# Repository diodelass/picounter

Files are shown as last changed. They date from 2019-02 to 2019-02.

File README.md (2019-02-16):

# PiCounter
## Frequency counter for experimental physics using the Raspberry Pi

### Overview
This repository holds schematics and information for the PiCounter, a firmwareless and fairly simple device for accurately measuring
the frequency of an electrical signal using the Raspberry Pi to control data collection. The device has the following features:
- Maximum count rate of up to 40 MHz
- 32-bit count capacity
- Two channels
- AND/OR coincidence mode for cosmic ray detection and similar applications
- Low total cost of manufacture
- Highly stable and accurate quartz-based counting gate timer
- 1/256-second counting time resolution
- Support for arbitrarily long counting times
- Side-mounted serial interface breakout for easy attachment of debug cables
- Support for external clock input

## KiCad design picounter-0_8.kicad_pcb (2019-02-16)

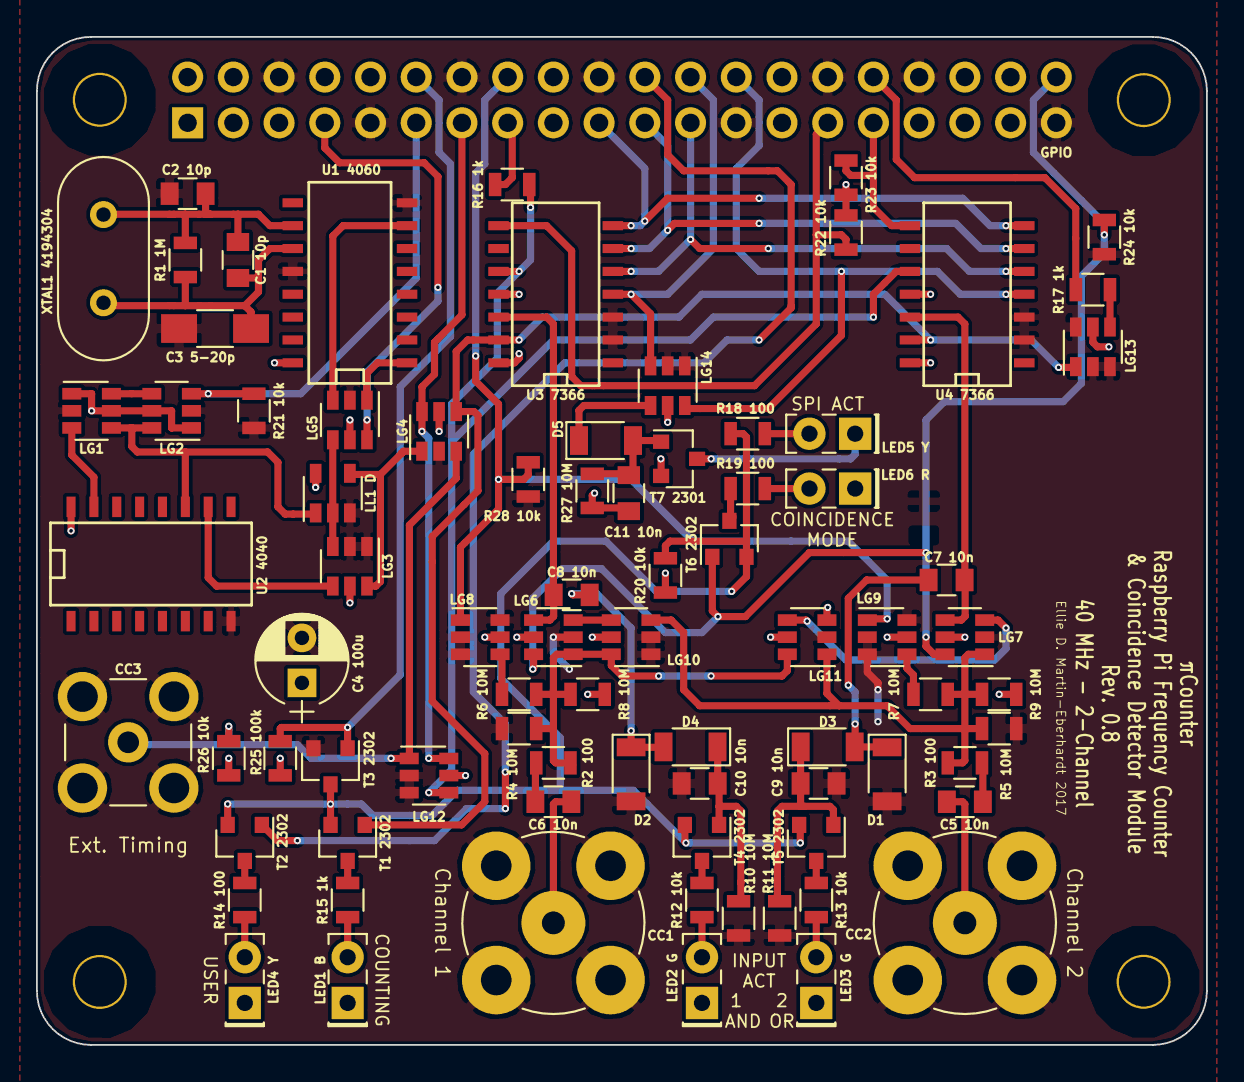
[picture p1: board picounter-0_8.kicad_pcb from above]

Board: 2 copper layers, 65.0 x 56.0 mm, 85 parts (1 on the bottom side), 2 nets.

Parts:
C1 10p, C2 10p, C5 10n, C6 10n, C7 10n, C8 10n, C9 10n, C10 10n, C11 10n: C_0805
C3 5-20p: C_1206_HandSoldering
C4 100u: CP_Radial_D5.0mm_P2.50mm
CC1, CC2: bnc-ci
CC3: SMB_Straight
D1, D2, D3, D4, D5: D_1206
GPIO: 40HAT; Socket_Strip_Straight_2x20
H1, H2, H3, H4: 3mm_Mounting_Hole; NPTH_3mm_ID
LED1 B, LED2 G, LED3 G, LED4 Y, LED5 Y, LED6 R: LED_Rectangular_W5.0mm_H2.0mm
LG1, LG2, LG3, LG4, LG5, LG6, LG7, LG8, LG9, LG10, LG11, LG12, LG13, LG14: SOT-23-6
LL1 D: SOT-23-5
R1 1M, R2 100, R3 100, R4 10M, R5 10M, R6 10M, R7 10M, R8 10M, R9 10M, R10 10M, R11 10M, R12 10k, R13 10k, R14 100, R15 1k, R16 1k, R17 1k, R18 100, R19 100, R20 10k, R21 10k, R22 10k, R23 10k, R24 10k, R25 100k, R26 10k, R27 10M, R28 10k: R_0805
T1 2302, T2 2302, T3 2302, T4 2302, T5 2302, T6 2302, T7 2301: SOT-23
U1 4060, U2 4040: SO-16-N
U3 7366, U4 7366: SOIC-14_N
XTAL1 4194304: Crystal_HC18-U_Vertical

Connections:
/P5V_HAT: C4 100u.1, C11 10n.1, GPIO.2, GPIO.4, LED1 B.1, LED2 G.1, LED3 G.1, LED4 Y.1, LED6 R.1, LG1.1, LG1.5, LG2.1, LG2.5, LG3.5, LG4.5, LG5.5, LG6.5, LG7.5, LG8.5, LG9.5, LG10.5, LG11.3, LG11.5, LG12.5, LG13.5, LG14.5, LL1 D.5, R8 10M.1, R9 10M.2, R20 10k.1, R22 10k.1, R23 10k.1, R25 100k.2, R26 10k.2, R27 10M.1, T7 2301.2, U1 4060.16, U2 4040.16, U3 7366.11, U3 7366.14, U4 7366.11, U4 7366.14
GND: C2 10p.2, C3 5-20p.2, C4 100u.2, C9 10n.1, C10 10n.1, CC1.2, CC2.2, CC3.2, D1.2, D2.2, GPIO.6, GPIO.9, GPIO.14, GPIO.20, GPIO.25, GPIO.30, GPIO.34, GPIO.39, LG1.2, LG2.2, LG3.1, LG3.2, LG4.2, LG5.2, LG6.2, LG7.2, LG8.2, LG8.3, LG8.6, LG9.2, LG9.3, LG9.6, LG10.1, LG10.2, LG11.2, LG12.2, LG12.3, LG13.2, LG13.3, LG13.6, LG14.1, LG14.2, LL1 D.3, R4 10M.2, R5 10M.2, R10 10M.2, R11 10M.2, R21 10k.1, R24 10k.1, R28 10k.1, T3 2302.2, U1 4060.8, U1 4060.12, U2 4040.8, U3 7366.2, U3 7366.3, U4 7366.2, U4 7366.3

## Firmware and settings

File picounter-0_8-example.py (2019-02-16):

#!/usr/bin/python3

# This script is for interfacing with the EIGHTH REVISION prototype counter board (version 0.8).

# Parameters
counttime = 1 #Floating point number of seconds to count for (resolution determined by configuration flag; see pin assignments)
brightness = 100 #LED brightness from 0 to 100

# import and set up modules: 
import RPi.GPIO as GPIO
import spidev
from time import sleep
from datetime import datetime
GPIO.setmode(GPIO.BCM)
GPIO.setwarnings(False)

# set GPIO pins to be used:
GPIO.setup(17,GPIO.OUT) # Trigger
GPIO.setup(12,GPIO.IN) # Counter enable watcher
GPIO.setup(18,GPIO.OUT) # Global LED power control
GPIO.setup(25,GPIO.OUT) # Yellow user LED
GPIO.setup(27,GPIO.OUT) # Internal/External clock selector
GPIO.setup(21,GPIO.OUT) # Coincidence mode select
GPIO.setup(4,GPIO.OUT) # 1 second or 1/256 second resolution selector
spi0 = spidev.SpiDev() # SPI bus for channel 0
spi1 = spidev.SpiDev() # SPI bus for channel 1
spi0.open(0,0)
spi1.open(0,1)
spi0.max_speed_hz = 5000 # SPI bus speed can be 250 MHz divided by any even integer between 2 and 65536 inclusive.
spi1.max_speed_hz = 5000 # As of revision 0.8, the SPI ACT LED should still visibly flash even on very high bus speeds.

# define control instructions for counter IC:
conf = [0x88,0x00]
read = [0x60,0x00,0x00,0x00,0x00]
zero = [0x20]

#### Pin Assignments:
#
#### GPIO 12 - CNT_EN - Monitors the status of the clock output. Has a 1K resistor attached in series to prevent low-impedance mishaps.
#		 	
#### GPIO 17 - TRIG - Triggers clock cycle when set high for "any" length of time. If held high when the count cycle would
#		       normally end, the count will continue for another full cycle time without pausing.
#		       As much as one millisecond and as little as zero milliseconds may pass between the assertion of the trigger
#		       and the start of the count interval; this depends on the phase of the clock and is not normally predictable.
#
#### GPIO 18 - PWR LED PWR - If set high, indicator LEDs on the board will be enabled. If set low, they will be disabled.
#			   This pin can be used as a PWM output to adjust brightness as necessary.
#
#### GPIO 27 - INT/EXT - If set high, the internal clock will be bypassed and the counters will instead accept active-high
#			   timing control from the connector labeled "Ext. Timebase" on the PCB.
#
#### GPIO 04 - TIME RES - Selects counter clock resolution, either whole seconds (low) or 1/256 seconds (high). In either case, the timing 
#			   interval will be the time the trigger pin remains high, rounded up to the nearest whole interval. Using 1/256 mode 
#			   requires at least 1/256-second precision for the time the trigger pin is held high. 
#
#### GPIO 21 - COINCIDENCE MODE - Puts the board into coincidence mode if set high. This will make the counter of channel 0 receive the 
#			   AND of the two inputs, and the counter of channel 1 receive the OR of the two inputs. The INPUT ACT LEDs will follow what 
#			   the counters are receiving at all times, so their behavior will change when coincidence mode is enabled - in coincidence
#			   mode, a pulse at either input will cause the LED on channel 1 (OR) to flash, and a simultaneous pulse at both inputs will
#			   cause both LEDs (AND and OR) to flash.
#
#### GPIO 25 - USER LED - This pin controls a yellow LED (labeled USER on the PCB) which can be used for arbitrary purposes. 

GPIO.output(4,0) # 1-second mode
#GPIO.output(4,1) # 1/256-second mode
GPIO.output(27,0) # internal clock
GPIO.output(17,0) # Trigger low
GPIO.output(18,0) # LEDs off
GPIO.output(21,0) # Coincidence mode off
#GPIO.output(21,1) # Coincidence mode on
GPIO.output(25,1) # USER LED on

# PWM for indicator LEDs
# Note that PWM stops when the program exits, so this will make all LEDs turn off when the program is not running.
indpwm = GPIO.PWM(18,10000)
indpwm.start(brightness)

spi0.xfer2(conf)
spi1.xfer2(conf)

#logfile = open(datetime.now().strftime('%Y-%M-%d_%H:%m:%S')+'.txt','w')
n = 0
try:
	while True:
		n += 1		
		#input('>> ') # Wait for enter key to be pressed before each count. Comment for continuous counting.
		spi0.xfer2(zero)
		spi1.xfer2(zero)
		GPIO.output(17,1)
		sleep(counttime-(0.5/256))
		GPIO.output(17,0)
		sleep(0.01)
		while GPIO.input(12): sleep(0.001)
		sleep(0.01)
		readtime = datetime.now().strftime('%Y-%M-%d %H:%m:%S')
		countbytes0 = spi0.xfer2(read)
		countbytes1 = spi1.xfer2(read)
		count0 = countbytes0[-1]+countbytes0[-2]*256+countbytes0[-3]*65536+countbytes0[-4]*16777216
		count1 = countbytes1[-1]+countbytes1[-2]*256+countbytes1[-3]*65536+countbytes1[-4]*16777216
		print('1:: ',int(count0))
		print('2:: ',int(count1))
		if count0 == 0 and count1 == 0:
			GPIO.output(25,1) # USER LED signifies zero counts obtained - very basic error reporting
		else:
			GPIO.output(25,0)
		#logfile.write(readtime+' :: '+str(int(count))+'\n')
finally:
	#logfile.close()
	GPIO.output(17,0) # Ensure trigger is low
	GPIO.output(25,0) # USER LED off
	#GPIO.cleanup()

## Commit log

2019-02-16 initial commit: added pcb file, pad assignments, and example python program
    [picounter-0_8.kicad_pcb]
2019-02-16 added footprint/package IDs to pad assignments

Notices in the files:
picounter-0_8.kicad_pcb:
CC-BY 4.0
